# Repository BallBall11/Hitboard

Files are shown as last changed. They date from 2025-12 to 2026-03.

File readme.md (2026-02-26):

### HITBOARD 开源项目

Hitboard 是一个开源 Hitbox 项目，包含 Zero、Air 等不用型号以适应不同用户、不同场景的需求。它诞生于一个简单的需求：为何不能有一台既拥有键盘的紧凑布局，又具备 Hitbox 专业输入体验的设备？

本项目不仅提供可生产的文件，更完整记录了从 设计思路、CAD布局、PCB工业化 到 固件配置 的全流程。你可以直接使用，也可以将其作为起点，打造属于你自己的终极武器。

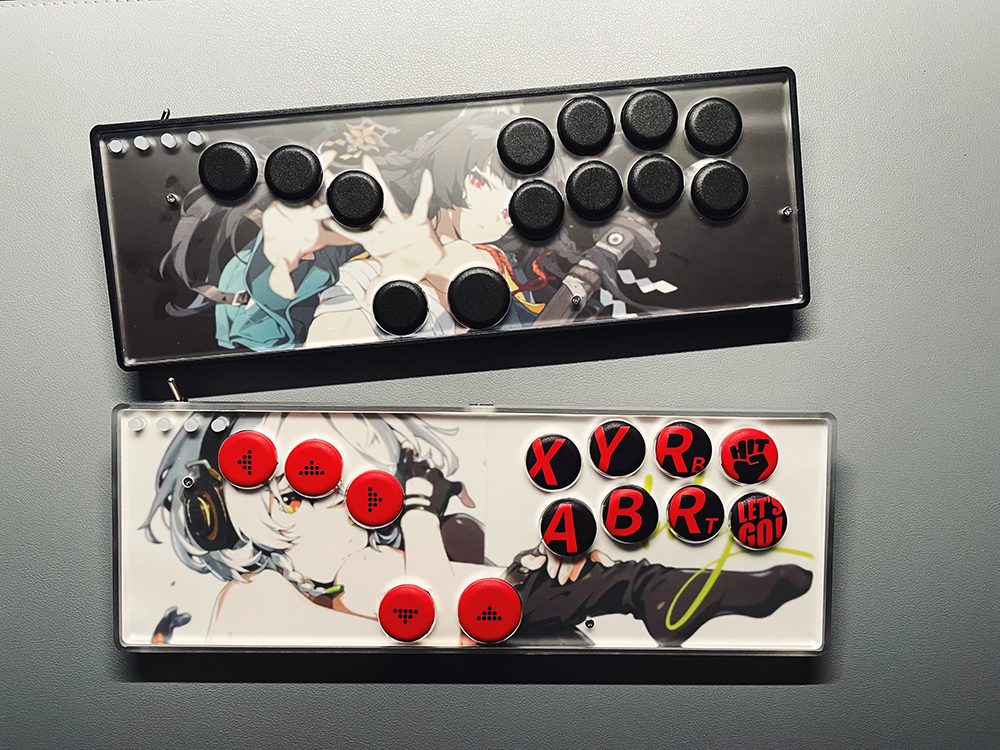
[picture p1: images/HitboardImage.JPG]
Hitboard成品图


#### 🎬 项目视频实录

本项目的完整诞生过程，已通过系列视频详细记录。如果你对背后的思考、踩坑的经历和具体的制作步骤感兴趣，强烈建议观看：

【【街霸6】180元手搓 Hitbox | 附材料清单设计源文件】 https://www.bilibili.com/video/BV1n8UQBeEs3/?share_source=copy_web&vd_source=521fa607e5f082de7ab25fcafb9cb9a2

【手搓Hitbox 第二弹：全程组装实录】 https://www.bilibili.com/video/BV15iUfBCE8V/?share_source=copy_web&vd_source=521fa607e5f082de7ab25fcafb9cb9a2

【手搓Hitbox 第三弹：生成CAD文件】 https://www.bilibili.com/video/BV1XumPBUEJE/?share_source=copy_web&vd_source=521fa607e5f082de7ab25fcafb9cb9a2

#### ✨ 型号说明
Hitboard Zero

从零开始的起点，为渴望亲手定义操控的创造者而生。纯亚克力多层结构，只需简单修改CAD文件即可调整布局，一切由你决定。这里仅提一套参考布局、PCB 源文件作为灵感，而非定死的答案。288×96mm键盘尺寸无缝融入桌面，双面壁纸让美学随你变换。它是你打造专属控制器的空白画布，也是通往深度定制的第一级台阶。

Hitboard Zero

Hitboard Air

像拼四驱车一样拼 Hitbox。基于3D打印技术实现，256mm宽度适配家用打印机。保留Zero的全尺寸按键布局，并提供更灵动的“拨片”加键。所有电路部分均为卡扣结构，可以方便的拆卸转移。

//由于卡扣结构的设计极其复杂，牵一发动全身。此型号提供全套 3D 打印文件作为标准答案。

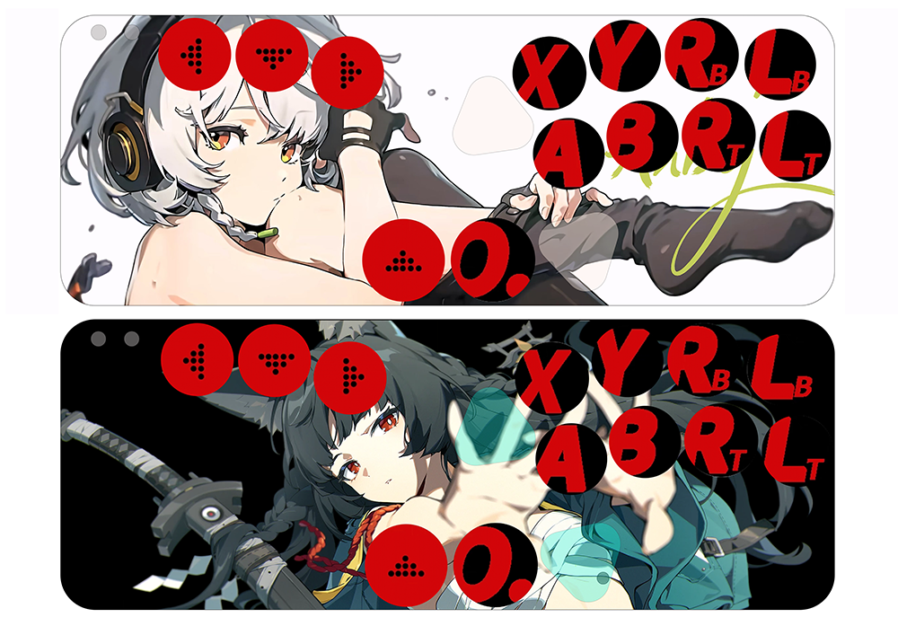
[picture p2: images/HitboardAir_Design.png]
Hitboard Air


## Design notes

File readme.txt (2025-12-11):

HITBOARD 开源项目

Hitboard 是一个专为键盘玩家设计的、高度紧凑、可完全自造的街机控制器（Hitbox）开源项目。它诞生于一个简单的需求：为何不能有一台既拥有键盘的紧凑布局，又具备 Hitbox 专业输入体验的设备？

本项目不仅提供可生产的文件，更完整记录了从 设计思路、CAD布局、PCB工业化 到 固件配置 的全流程。你可以直接使用，也可以将其作为起点，打造属于你自己的终极武器。

Hitboard成品图

🎬 项目视频实录
本项目的完整诞生过程，已通过系列视频详细记录。如果你对背后的思考、踩坑的经历和具体的制作步骤感兴趣，强烈建议观看：

【【街霸6】180元手搓 Hitbox | 附材料清单设计源文件】 https://www.bilibili.com/video/BV1n8UQBeEs3/?share_source=copy_web&vd_source=521fa607e5f082de7ab25fcafb9cb9a2

【手搓Hitbox 第二弹：全程组装实录】 https://www.bilibili.com/video/BV15iUfBCE8V/?share_source=copy_web&vd_source=521fa607e5f082de7ab25fcafb9cb9a2

【手搓Hitbox 第三弹：生成CAD文件】 https://www.bilibili.com/video/BV1XumPBUEJE/?share_source=copy_web&vd_source=521fa607e5f082de7ab25fcafb9cb9a2

✨ 项目特点
键盘布局，零学习成本：基于 GH60 键盘壳尺寸，沿用最熟悉的打字手位，上手即用。
全开源可定制：提供所有原始设计文件（CAD/PCB），你可以自由调整每一个按键的位置。
工业化 PCB 设计：采用专业 PCB 替代飞线，集成 WS2812B LED 灯带支持，稳定且易于焊接。
GP2040-CE 原生支持：完美兼容开源固件 GP2040-CE，享受持续的功能更新与强大的社区支持。
模块化设计：预留背光、热插拔摇杆模块接口，功能可自由增减。

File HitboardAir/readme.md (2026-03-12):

### Hitboard Air - 组装指南

### 准备工作：采购元器件

1. 下载网页工具：00_设计你的 Hitboard Air.html

2. 用浏览器打开该网页，设计你的 Hitboard。设计完成后，点击页面中的「导出产品配置」按钮，导出你的配置图片。

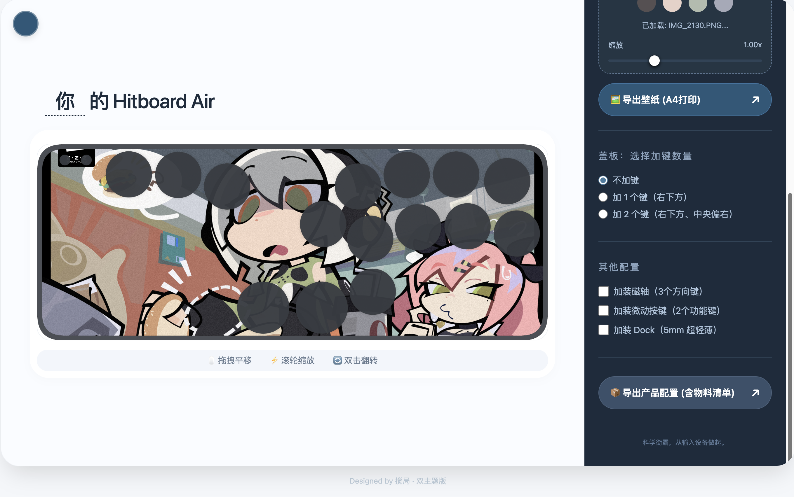
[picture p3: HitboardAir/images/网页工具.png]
HitboardAir 全部打印件


3. 根据配置图片中的物料清单，采购元器件、3D 打印套件。

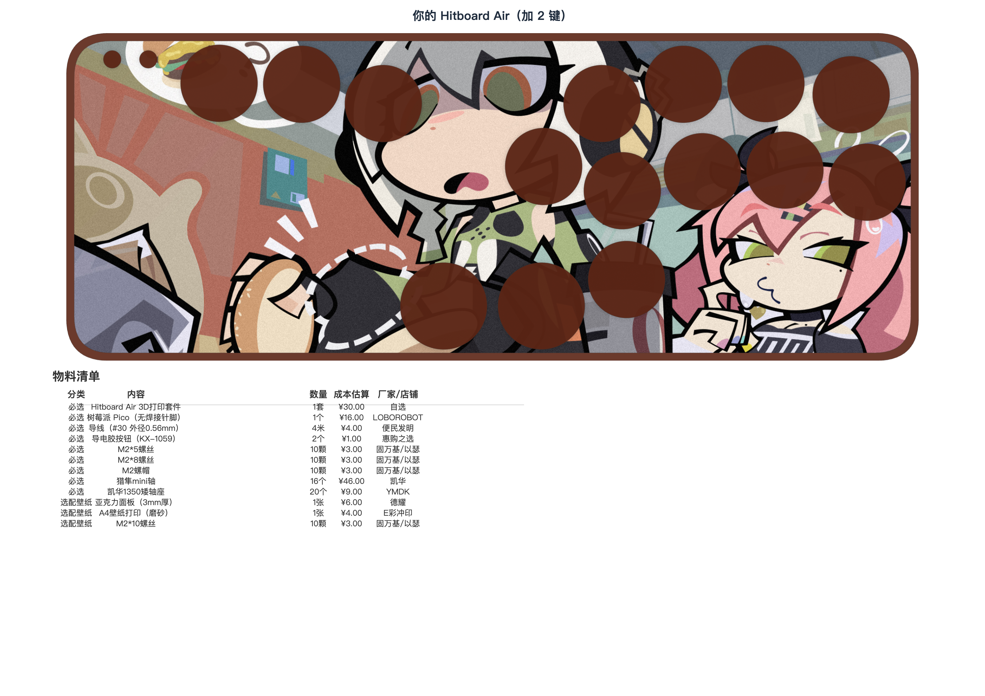
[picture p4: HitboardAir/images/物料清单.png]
HitboardAir 全部打印件


**3D 打印文件怎么选**

02_3D_Files 目录，包含两套 3D 打印文件，分别是：

「Hitboard Air - 圆润版」

「Hitboard Air - 硬朗版」

//两个版本只有外壳、按键的弧度有区别，内部零件通用。根据你喜欢的风格二选一，或全都选，即可。

HitboardAir 全部打印件

### 组装过程

### 第一步：给 Pico 刷入 GP2040 固件

1. 按住 Pico 复位按钮的同时，通过 typec 数据线连接 Pico 到电脑。此时 Pico 将会以 U 盘的形式出现。
    
2. 将固件「GP2040-CE_0.7.12_Pico.uf2」文件，拖拽到 Pico U 盘。
    
3. 等待几秒钟，Pico 会被重新识别为手柄。可以在手柄测试网页 https://hardwaretester.com/gamepad 查看手柄状态，用导线短接 GND 和任意信号引脚查看是否工作。

### 第二步：飞线连接元器件

打开「Pico背面图片」，观察的引脚示意图，了解引脚的基本情况。

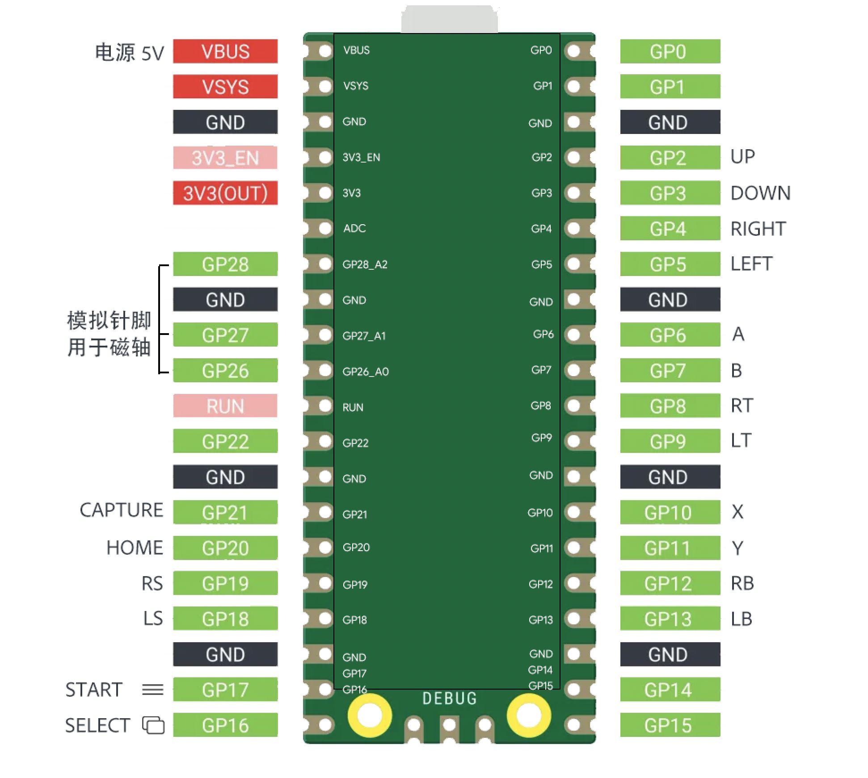
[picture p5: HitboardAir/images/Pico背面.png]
HitboardAir 全部打印件


1. 拿出「Hitboard Air 03 线路板」，板子上布满卡扣，依次将 Pico、轴座卡在对应的位置。

**注意！一定要是正面（有 USB 凸起）朝里，背面（绿色纯平面）朝向自己卡进去。**

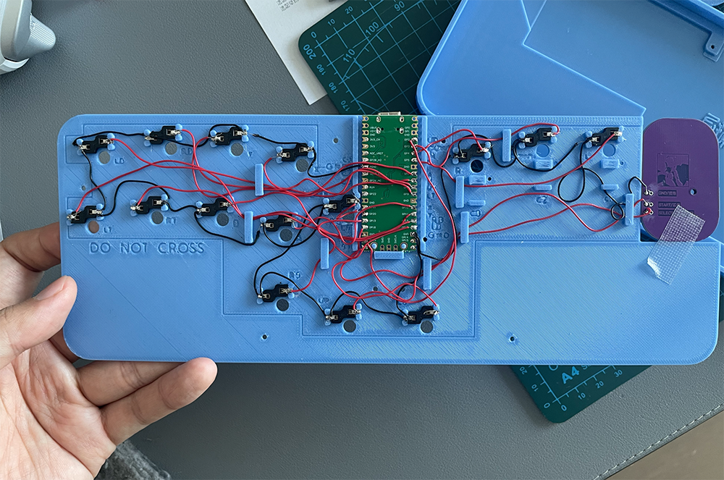
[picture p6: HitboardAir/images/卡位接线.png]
HitboardAir 全部打印件

    
2. 连接
    
    首先，留意线路板上的“警戒线”标注，警戒线内对应底壳空腔，表示线路可以被容纳。如果超出警戒线，则线路无法被容纳，组装时，无法放平整。

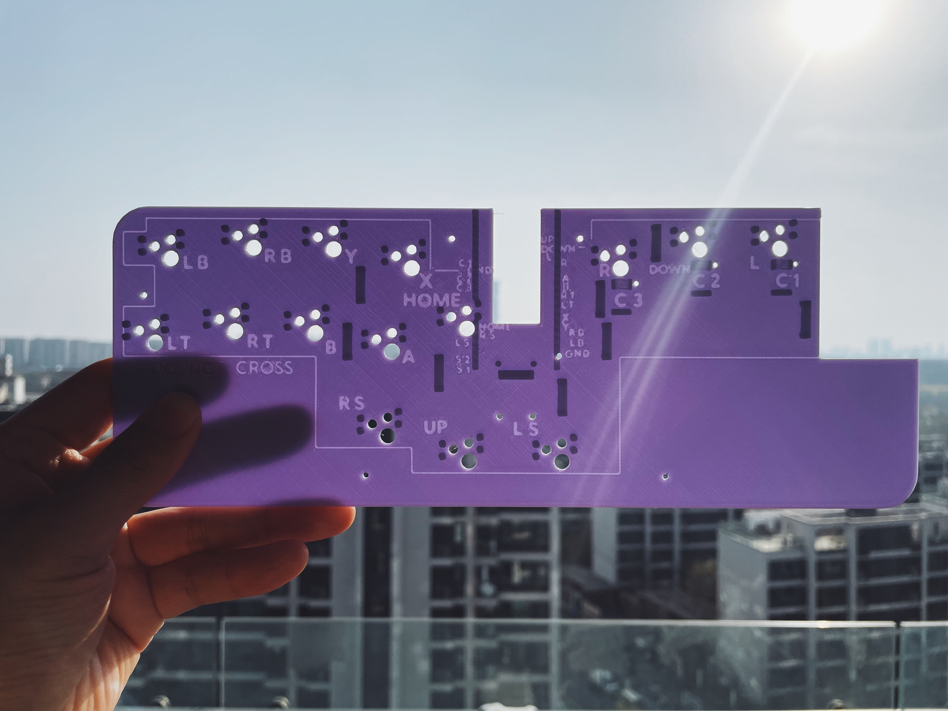
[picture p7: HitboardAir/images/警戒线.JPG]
HitboardAir 全部打印件


先来给每个按键接 GND。
    
    从 Pico 的任意 GND 方形焊盘，引出导线，将导线依次通过每一个轴座的任一引脚，焊接确保联通（或者缠绕连接）。这样就完成了按键的接地。
        
    将按键轴座另外一个引脚，接到对应的功能。比如方向键「Up」连接到 GP2 Up。
        
    把 4 个方向键、8 个功能键的轴座触点，通过导线，连到 Pico 对应的引脚。
        
    三个加键的轴座触点，连到 Pico 的 LS、RS、Home 引脚，后续需要在设置中，改为你需要的其他按键。

    Select、Start，默认使用导电胶+小电路板实现。把电路板上对应名字的焊盘，与 Pico 引脚相连即可。记得给小电路板连 GND。
        
    // 连接完成后，务必把 Pico 连接到电脑，用导线短接每个轴座的两个引脚。在手柄测试网页查看是否都能生效。
        
    // 如果不生效，检查是否虚焊，直到所有按键电路都正常工作。

### 第三步：组装所有板子

    将 03线路板、02定位板，依次放入04外壳。
    
    将轴体压入 02 定位板。//可以用手指挤压轴体左侧的外壳，让轴体不损耗卡扣
    
    放置导电胶按钮。
    
    准备盖板。通过 04 外壳的卡扣卡好即可。
    
    // 如果想要更牢固的固定盖板：
    
        先将 M2 螺丝帽，放入盖板背面的隐藏式螺帽仓。
    
        盖好盖板到外壳。
    
        从外壳背面，拧 6 颗 8mm M2 螺丝。
    
    从00按键中，取下按键，对应按键位置，一一装入。

### 软件设置

#### 按键配置

1. 按住 Start 按键的同时，通过 typec 连接电脑。
    
2. 访问 GP2040 Web 配置界面（通过 USB 连接后访问 192.168.7.1）
    
3. 点击「功能配置-GPIO 引脚配置」，将 LS、RS、Home 等按键，改为需要的按键。
    
    如果忘了哪个按键对应哪个。点击网页中的「引脚查看器」按钮，在 Hitboard 上按下需要配置的按键，网页会显示引脚编号（如果第一次检测无效就关闭弹窗再次点击）。
        
    在按键列表中找到对应的引脚，编辑按键即可。
        
#### 手柄性能设置：//必做

1. 点击「设置-游戏手柄设置」。
    
2. 将 SOCD 清理模式，改为「后输入优先」。
    
3. 将去抖延迟，改为 0 毫秒。

### 选配组件

#### Dock

先把本体滑入Dock上半。（滑入前，将 2 颗 M2 螺帽装入上半螺帽仓）

再把Dock下半卡入本体。

将 5mm M2 螺丝，分别从 Dock 左右两侧的螺丝孔拧入，即可完成固定。

锁线器：
    
    将 12 颗小磁铁，6 颗一组，压入锁线器的磁铁仓。
    
    将 6 颗小磁铁，3 颗一组，压入 Dock 的磁铁仓。
    
    将锁线器快装到 typec 数据线，即可使用磁吸锁线功能。

#### 盖板和壁纸

通过网页工具，制作下载壁纸图片。以 A4 尺寸打印，获得纸质壁纸。

对壁纸裁剪、打孔，取下 3D 打印盖板，替换为壁纸、亚克力盖板即可。

// 亚克力生产的 CAD 文件：其他/CAD 文件/Hitboard Air 亚克力.dwg

#### 磁轴

星磁mini轴的弹簧比较硬，我们先对弹簧手感进行调优。

剥开轴体，取下弹簧。将弹簧剪掉1/3。剪下的弹簧不要丢掉，以后可以用在功能键上。磁轴结构非常简洁，圆形磁铁对准圆形磁铁孔，装回即可。

这样轴体的手感就非常丝滑软弹了。如果想要磁轴、机械轴共存，剪掉磁轴右上方的塑料卡针即可。

搞定机械部分之后，我们开始处理电路。拿出选配零件中的霍尔传感器。窄面朝上，卡入线路板专用位置。传感器从右边起，分别是信号引脚、GND、3V3电压输入。每个传感器一一对应连接。

然后进入最后的软件校准环节。进入网页配置界面，
先进入LED配置，把默认占用的28引脚修改为其他引脚，释放这个模拟引脚。

然后进入插件设置，确保其他设置没占用模拟引脚的情况下，进入霍尔设置。

设置直连，26、27、28。然后对每个引脚绑定手柄键值，然后校准。

这里可以设置一个比较短的触发行程，让方向键快于拳脚键。对搓招儿的时间窗口比较有利。

最后保存触发值，重启设备。你的 Hitboard 就拥有了最顶级的性能。

### 关于手工缠线（免电烙铁）

手工缠线比电烙铁还要简单。要点是小孔缠线的技巧。
掐掉导线20cm左右的绝缘皮，对折导线头。

穿入对应的引脚焊盘孔，旋转Pico或导线，你就获得了由四股导线固定的引脚线
比单根导线有更大的强度和更大的接触面积。

绑定所有导线后，像装机走线那样集中安排走线就行了。

轴座端，缠两圈线，压扁轴座铁皮，一路引脚就固定好了。

轴座新增2个小过孔，方便GND裸导线从背面走线。

之后就是重复操作，不再赘述。

### 总结

我们从一堆散件开始，亲手完成了固件烧录、线路连接、整机组装和软件配置。最终得到的，不只是一台Hitboard——更是从零到一，把想法变成实物的能力。

科学街霸，从输入设备做起。Hitboard，让创造回归简单。

**【完】**

项目贡献者名单：@搅局无敌 @JennyPeng @匈牙利山猫 @Rev01ution

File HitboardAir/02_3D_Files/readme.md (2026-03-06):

### Hitboard Air - 3D打印设置

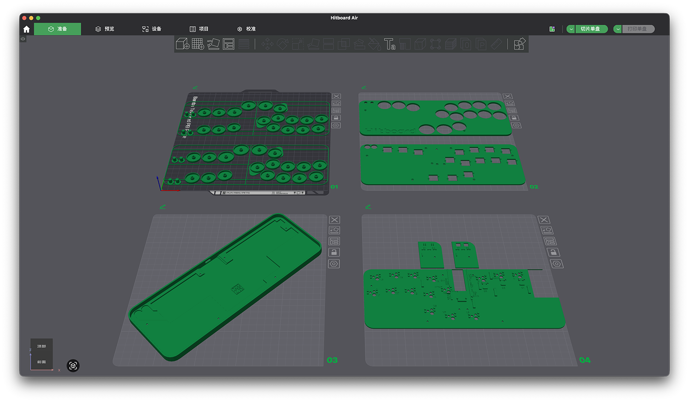
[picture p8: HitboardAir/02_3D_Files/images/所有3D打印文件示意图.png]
HitboardAir 全部打印件


#### 1. 文件说明

#### Hitboard Air 双版本 · 刚柔并济

**文件说明**

Hitboard Air 提供两种性格的版本——刚版与柔版。外壳、按键、Dock 三处的倒角设计，决定了设备整体的气质与手感。你可以根据自己的偏好，选择与你契合的那一款。

**刚 · 方正利落**
    
平整的极客体验。

    边缘干脆，线条直接。2.4mm 倒角仅做必要圆滑，保留直角带来的精准感。适合追求硬朗风格、喜欢清晰反馈的你。放在桌上，它是一块冷峻的金属感面板；握在手里，每一个棱角都在提醒你：这是一件趁手的工具。

**关键词：** 利落、精准、克制

**柔 · 圆润亲和**

温润的舒适体验。

    圆角过渡自然，握持更贴合手掌。每一个边缘都经过细致打磨，触感如鹅卵石般温润。适合长时间使用、偏爱柔和手感的你。它不会喧宾夺主，只是安静地承托你的每一次操作。

**关键词：** 圆润、舒适、包容

选择你的版本

刚与柔，没有好坏，只有不同。你的设备，该有你的性格。

##### 00_按键

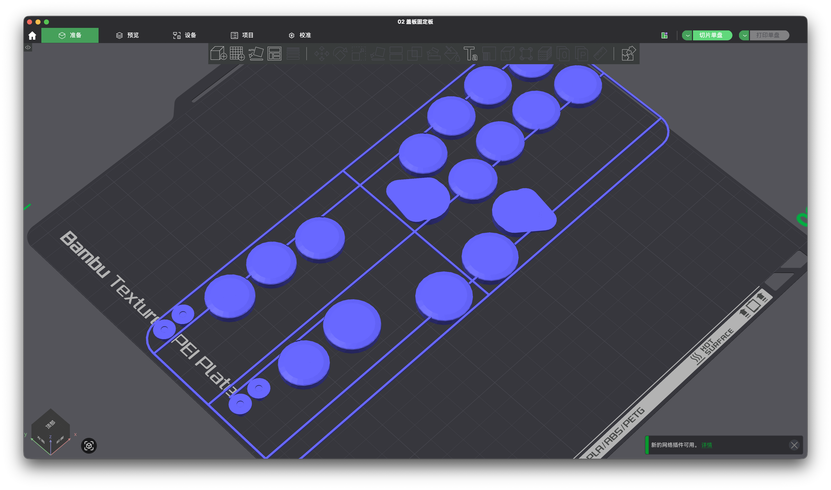
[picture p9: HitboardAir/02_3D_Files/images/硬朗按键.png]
HitboardAir 有刻键帽


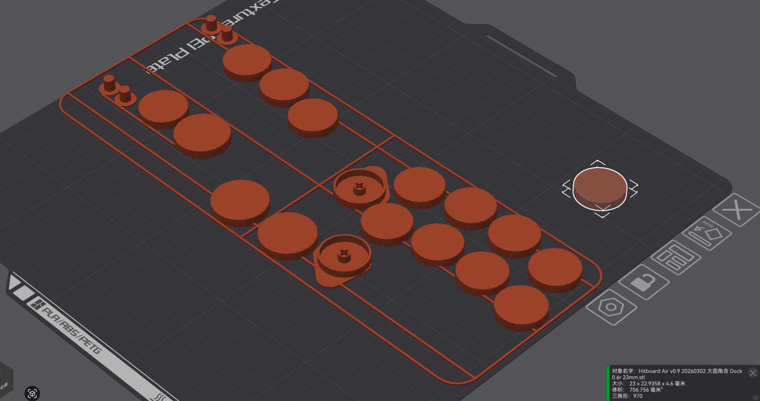
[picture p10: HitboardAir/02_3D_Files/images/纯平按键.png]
HitboardAir 有刻键帽


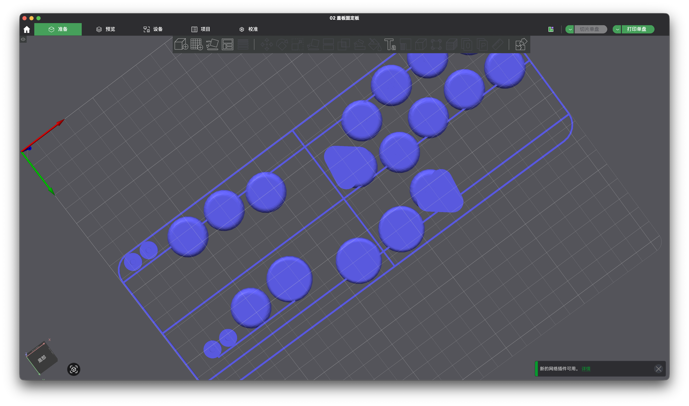
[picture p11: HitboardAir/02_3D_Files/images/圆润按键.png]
HitboardAir 有刻键帽


**键帽类型**

按键类型    命名    英文名    说明
2.5mm斜切    硬朗按键    Edge Key    线条硬朗，反馈清晰
0.6mm圆角    纯平按键    Flat Key    视觉纯平，手感顺滑不割手
3mm圆角    圆润按键    Round Key    明显圆角，手感柔和

**键帽触感**

按键根据键帽的朝向，有键帽朝上（正打）、键帽朝下（反打）两种方式。

正打能提供比较好的表面平整度，缺点是按键的确认感会不清晰。

反打按键的特点是，利用热床的颗粒，反打获得的表面随机颗粒效果，可以欺骗触觉（类似相机上的颗粒喷涂）。

// 注意：反打按键，需要在软件里把文件翻个朝向（也可以点击软件的「自动朝向」）。

**键帽刻字**

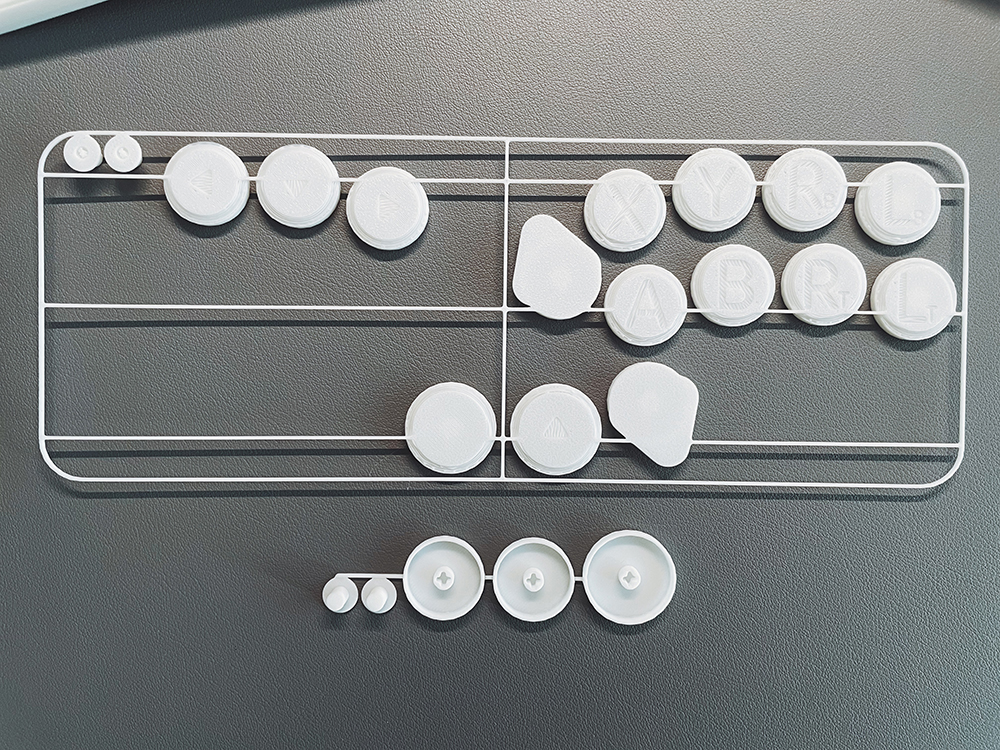
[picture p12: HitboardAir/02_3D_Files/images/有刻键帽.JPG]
HitboardAir 有刻键帽


有刻按键整体视觉上会好看一些，但会牺牲手感。推荐无刻。 （有刻在 More 文件夹中，有需要的自取）

##### ButtonsSystem

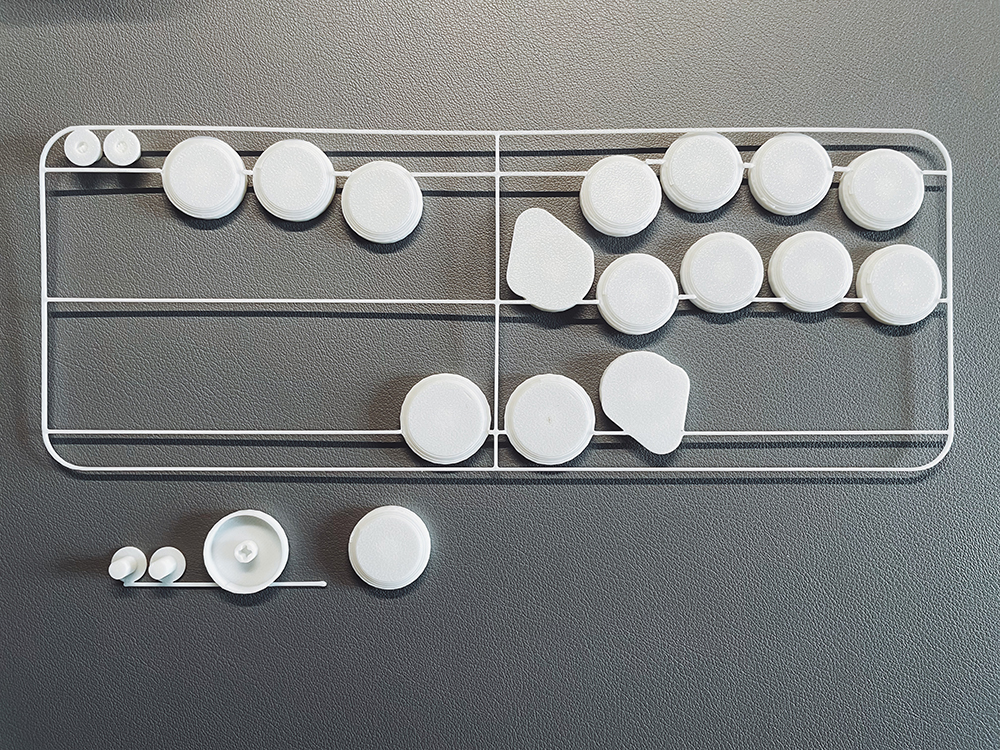
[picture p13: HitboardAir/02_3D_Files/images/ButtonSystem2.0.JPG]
HitboardAir 有刻键帽


按键通过中框串联，不会掉的到处都是。能一定程度防止运输过程丢按键。每套按键都提供了一组独立的备用按键，包含 2 个功能键、1 个 23mm 按键，1 个 26mm 按键。
        
中框已升级为 ButtonsSystem2.0，可以轻松的从框体取下键帽。喜欢拼高达，喜欢口水钳剪零件的同学可以打印这两套按键。

ButtonsSystem 已适配的按键组：
    
    00_Hitboard_Air_硬朗按键_全按键_无刻_带框_反打

    00_Hitboard_Air_圆润按键_全按键_无刻_带框_反打

##### More 文件夹

提供了更多的按键选项，进阶 3D 打印玩家可以多尝试不同的组合。

// 后续会持续研究 3D 打印按键，欢迎大家反馈这方面的需求。

#### For A1mini 180x180 文件夹

** 之后会适配 Amini 打印机的 180x180 尺寸，让每一个人都能享受到科技乐趣。 

** 01_盖板

用作产品上盖。
// 如果有自定义壁纸的需要。可以拿 CAD 文件，去花几块钱买一个 3mm 磨砂亚克力盖板。

盖板新增了 Logo
    
        “跟人约战街霸，对方没听过 Hitboard。你掏出设备，一个没有 Logo 的 3D 打印件——对方看了一眼，没说话。”

        “你知道他在想什么：山寨货。”

        “尴尬。”

        “Logo 不一定为了让别人认出来。有时候，是为了不让别人认错。”

** 02_定位板

// 定位板、轴座板，支持凯华矮轴：猎隼 mini、紫鸳、孤岛粉 mini、星磁 mini 等

用于支撑、固定机械轴。
    
安装轴体时，可以用手指按紧机械轴左侧的塑料臂，然后再往里按。这样能有效提升卡位结构的寿命。

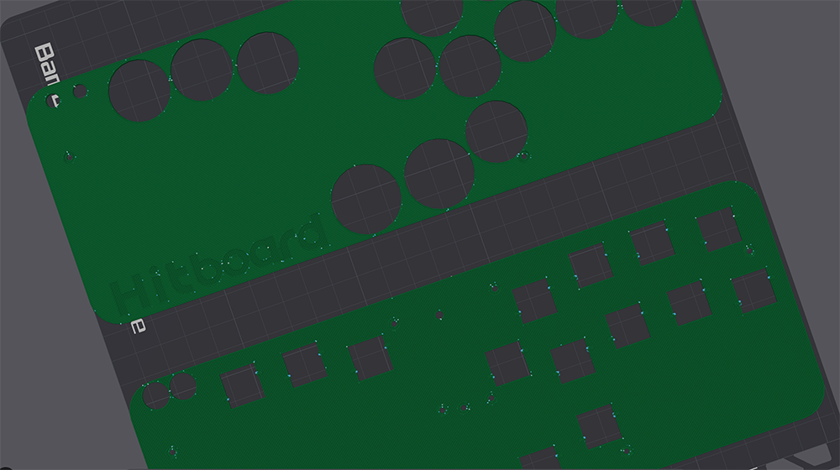
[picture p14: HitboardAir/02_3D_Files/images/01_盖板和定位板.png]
HitboardAir 按键


** 03_线路板
    
用于安装轴座、Pico 主板、飞线、功能键微动按钮。
    
线路板有凹印文字，标记了引脚。飞线时可参考标记接线。
    
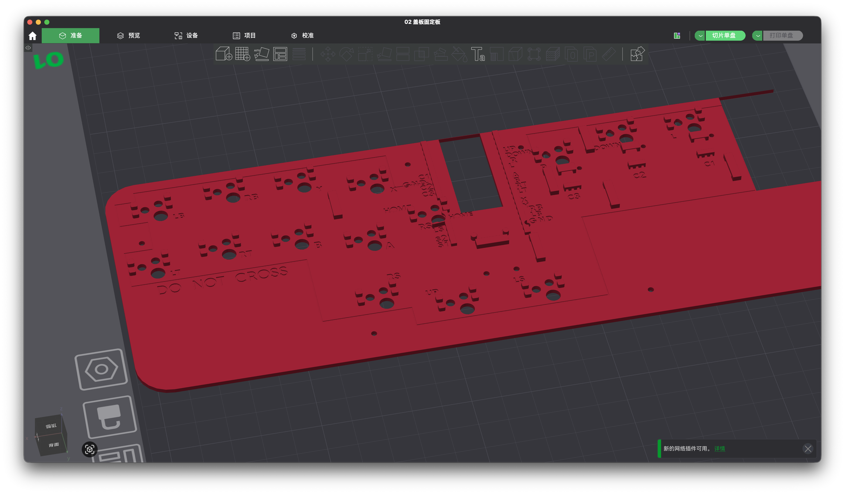
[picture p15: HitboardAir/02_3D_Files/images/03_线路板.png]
HitboardAir 线路板

    
「more」目录，提供了单独的「功能键小板」文件。方便单独补零件。

** 04_底壳
    
底壳提供 9.3mm（超薄）、9.7mm（中薄）两个文件。
    
这里优先推荐 9.3mm 外壳，因为 9mm 左右恰好能让键盘的厚度没有存在感，不硌手。9.7mm 的厚度，键盘底部边缘会有存在感，请知。

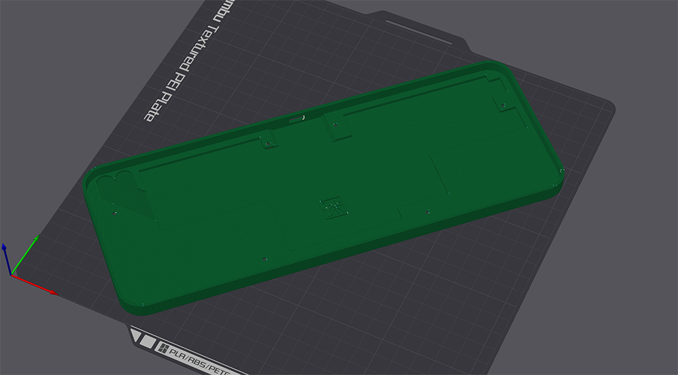
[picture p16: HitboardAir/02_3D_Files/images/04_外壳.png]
HitboardAir 按键


关于边框：默认提供 2.4mm 的边框，能让彩色外壳线条更美观。//more 文件夹有原 2mm 边框，有需的自取。两种边框外圈都是一样大（260x100）

#### 2. 打印设置

** 支撑设置

01、02、04 板子，按默认面打印。00按键、03板子，需要在打印软件里翻个面。// 点击拓竹的自动翻面就可以

用不用支撑差别不大，可以开启树状支撑保险一点。

// 经常为了赶时间开狂暴模式打印，狂暴模式下出品质量也可以，因为基本都是垂直件没有悬浮。

** 朝向设置

04 外壳，倾斜 45 度打印，能让打印机的纹路横竖走，而不是 45度倾斜走。这样纹路会更方正、更有稳定感。。

00、01、02、03，用默认的朝向打印，45 度纹路，视觉上减少存在感。

#### 3. 打印材料

Hitboard Air 是基于 PETG 材料设计，有足够的强度和耐久度，计划长时间使用的话推荐使用 PETG 作为打印材料。

// 鉴于很多人的 3D 打印机只能打 PLA，对 PLA 也做了打印测试：精度、强度都还不错。长时间使用耐久度待观察。

// 注意！PLA 高温下容易形变，打印完成后，务必等板子冷却后，再取。否则可能会让板子弯曲。

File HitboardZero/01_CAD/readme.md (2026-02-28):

### Hitboard Zero CAD 使用说明

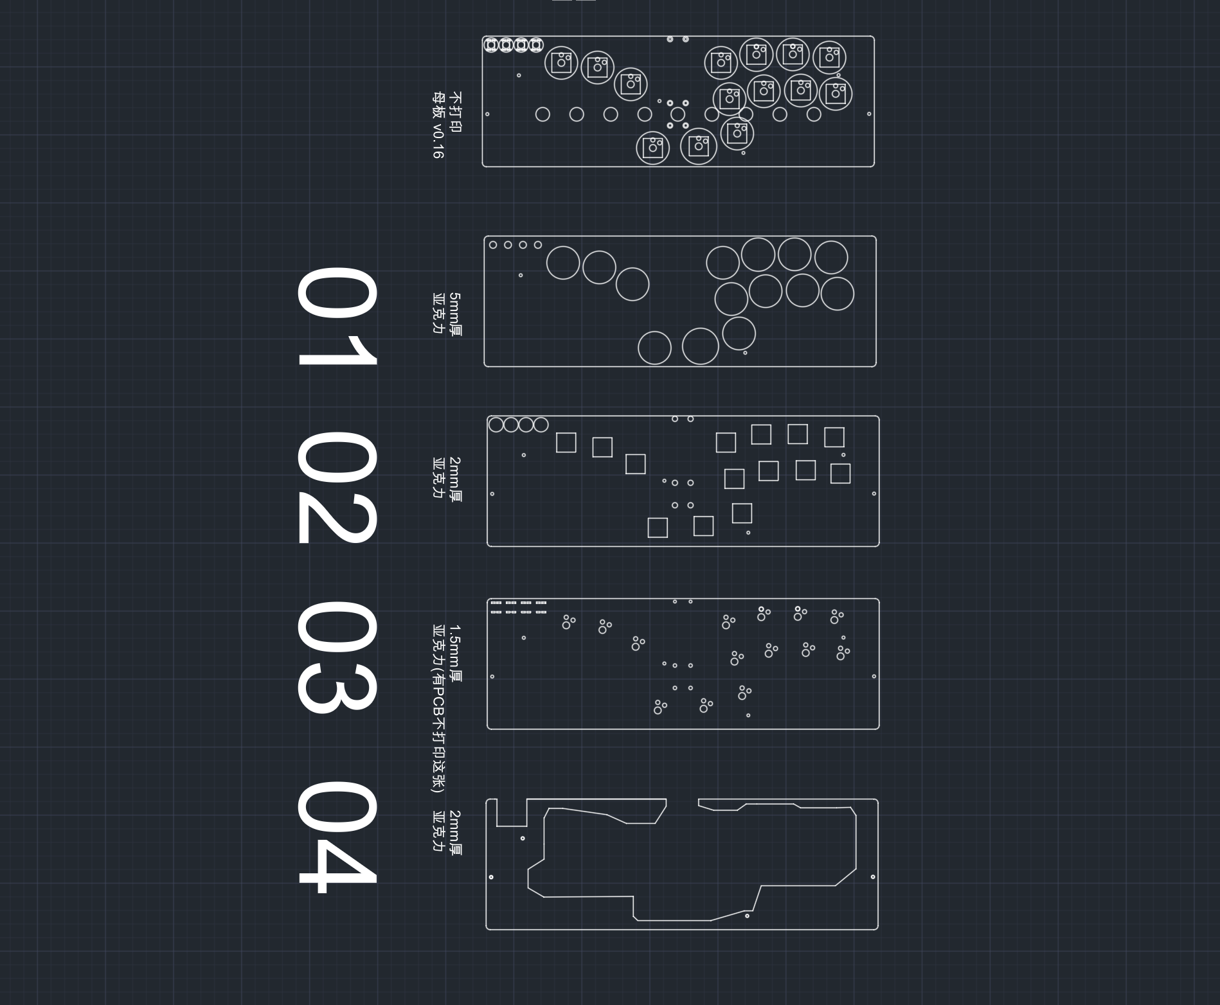
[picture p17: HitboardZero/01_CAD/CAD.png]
Hitboard成品图


#### 01 盖板

3-5mm 厚

放在顶层起到支撑手掌和展示壁纸的作用。一般采用透明亚克力或磨砂亚克力材质。

// 如果是亮色的壁纸，磨砂亚克力可以很好的柔光。如果是暗色的壁纸，透明亚克力可以让黑色更深沉。

#### 02 定位板

2mm 厚

14x14 的开孔，用于固定键盘轴体，并支撑敲击按键时的力。
// 中间有两组开孔，用户容纳螺丝的螺帽。

#### 03 轴座板

1.5mm 厚

用于支撑机械轴的轴座。将轴座插入每个按键的两小孔，并使用胶水固定。
// 中间两组螺丝孔，用于固定 pico。

#### 04 支撑板

2mm 厚

用于制造空腔，容纳轴座、pico、飞线。

// 顶部横梁默认是不断开的，提供更好的支撑性。如果是 typec 中央开孔，可以自行剪断。

#### 05 底部壁纸板

1mm 厚

用于支撑壁纸。//背面不放壁纸就不需要打印

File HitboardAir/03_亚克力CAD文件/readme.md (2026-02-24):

### Hitboard Air - CAD 说明
文件中为 Hitbox 的盖板。提供了 A、B、C 三个型号：

    A 带有两个加键（右手大拇指右侧、A 与 X 的左侧）

    B 只带一个加键（右手大拇指右侧）

    C 不带加键

// 下单无需 CAD 程序，根据型号列表报给商家就可以。

// 定位板是按照 2 个加键设计的卡位凸起，如果选择了 B、C 盖板，把定位板上的凸起剪掉就可以。

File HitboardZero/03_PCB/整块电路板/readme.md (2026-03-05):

### Hitboard Zero PCB（电路板） 说明 

鉴于市面上的 GH60 壳子五花八门，不规格。忙完这一阵子，会集中出一个高兼容性的 PCB。

敬请期待。

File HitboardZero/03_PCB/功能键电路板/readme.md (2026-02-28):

### Hitboard Zero PCB（电路板） 说明
使用亚克力和飞线作为电路

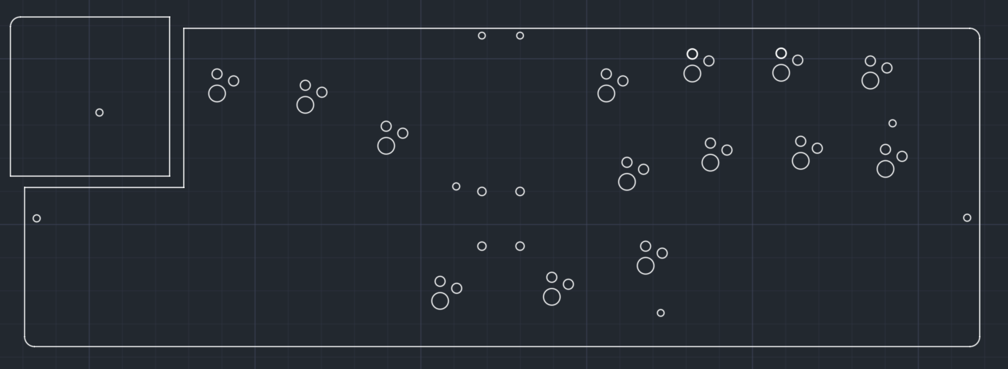
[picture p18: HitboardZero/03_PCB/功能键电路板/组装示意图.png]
Hitboard成品图


「03 轴座板」左上角设计了一个 48x48 的缺角。只需要使用嘉立创免费券，打印一个 48x48 的功能键电路板，就可以替代掉之前铜箔胶带贴电路的操作，更简单、更稳定。

// 推荐最开始使用飞线方案。因为把 Pico 焊接到 PCB 之后，几乎无法无伤拆解。等验证找到适合自己的布局之后，再考虑 PCB。

// PCB 相比飞线，所需要的焊点数量是一样的，并不会省时间。PCB 制造耗能、耗材料，不环保，不建议使用大块的 PCB。

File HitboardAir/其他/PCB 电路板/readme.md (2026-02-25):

### Hitboard Air - PCB（电路板） 说明
Hitboard Air 的设计初衷是模块化组装，飞线连接。不需要整块的电路板。

加入小电路板的目的是，让小朋友或者萌新能接触到最简单的PCB电路，对电子工程产生一些模糊的概念。

// 3D 打印文件，03 线路板中附带的「功能键零件」不论是手搓导电电路，还是使用微动按键，都能实现很好的功能键体验。

// 可以不使用此 PCB。

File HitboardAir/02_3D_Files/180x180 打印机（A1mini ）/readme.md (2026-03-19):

### Hitboard Air - For A1mini

20260319
-大幅增强了 A1mini 版本的结构强度。

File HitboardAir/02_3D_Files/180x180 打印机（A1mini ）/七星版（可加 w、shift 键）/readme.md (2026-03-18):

### Hitboard Air - For A1mini

00 按键、04 外壳，分为硬朗版和圆润版，根据自己的喜好二选一，或全都选。

01 盖板、02 定位板、03 线路板，是硬朗、圆润通用的，逐个打印。

// 盖板文件中，有全套封帽（包括摇杆封帽），根据自己需求自定义。
// 需要更多配件，去：HitboardAir/More - 更多配件/

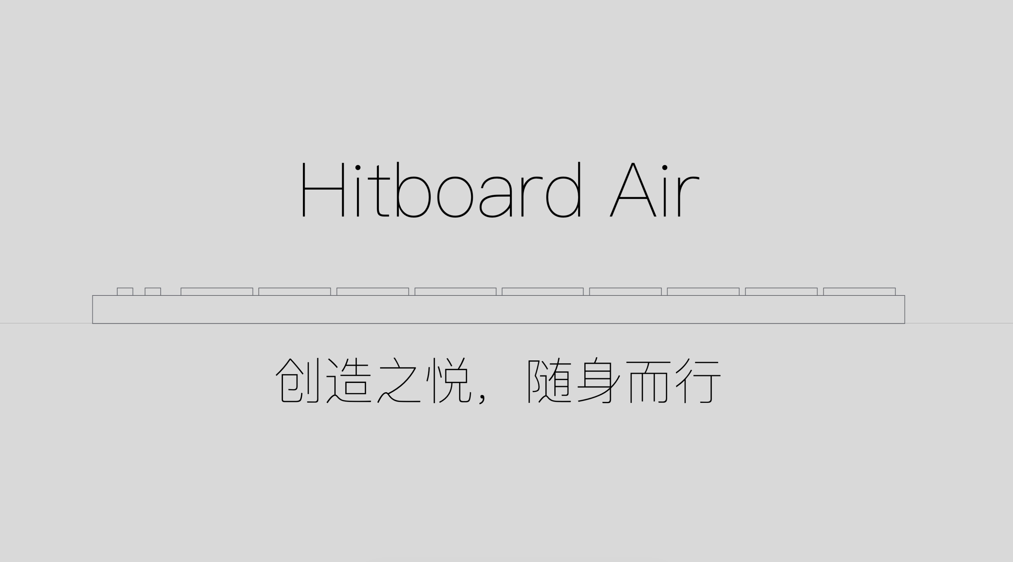
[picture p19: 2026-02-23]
HitboardAir/images/封面.png

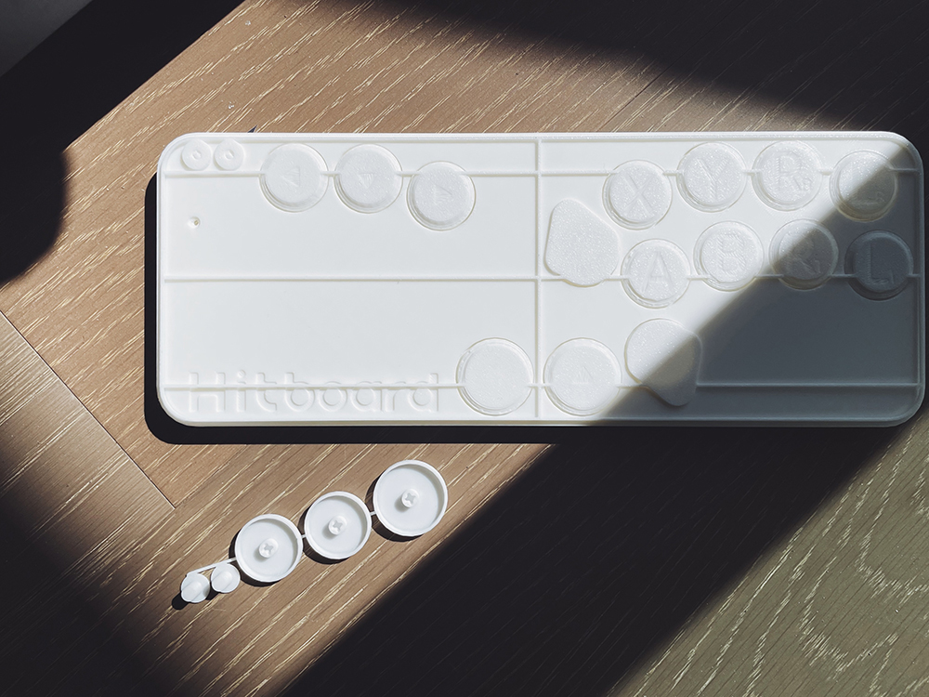
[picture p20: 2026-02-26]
HitboardAir/02_3D_Files/images/产品实拍_PLA.jpg

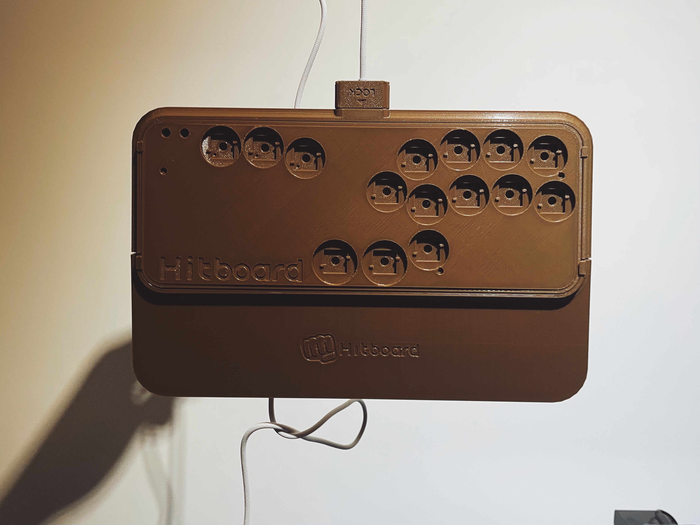
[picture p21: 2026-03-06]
HitboardAir/images/Dock.JPG

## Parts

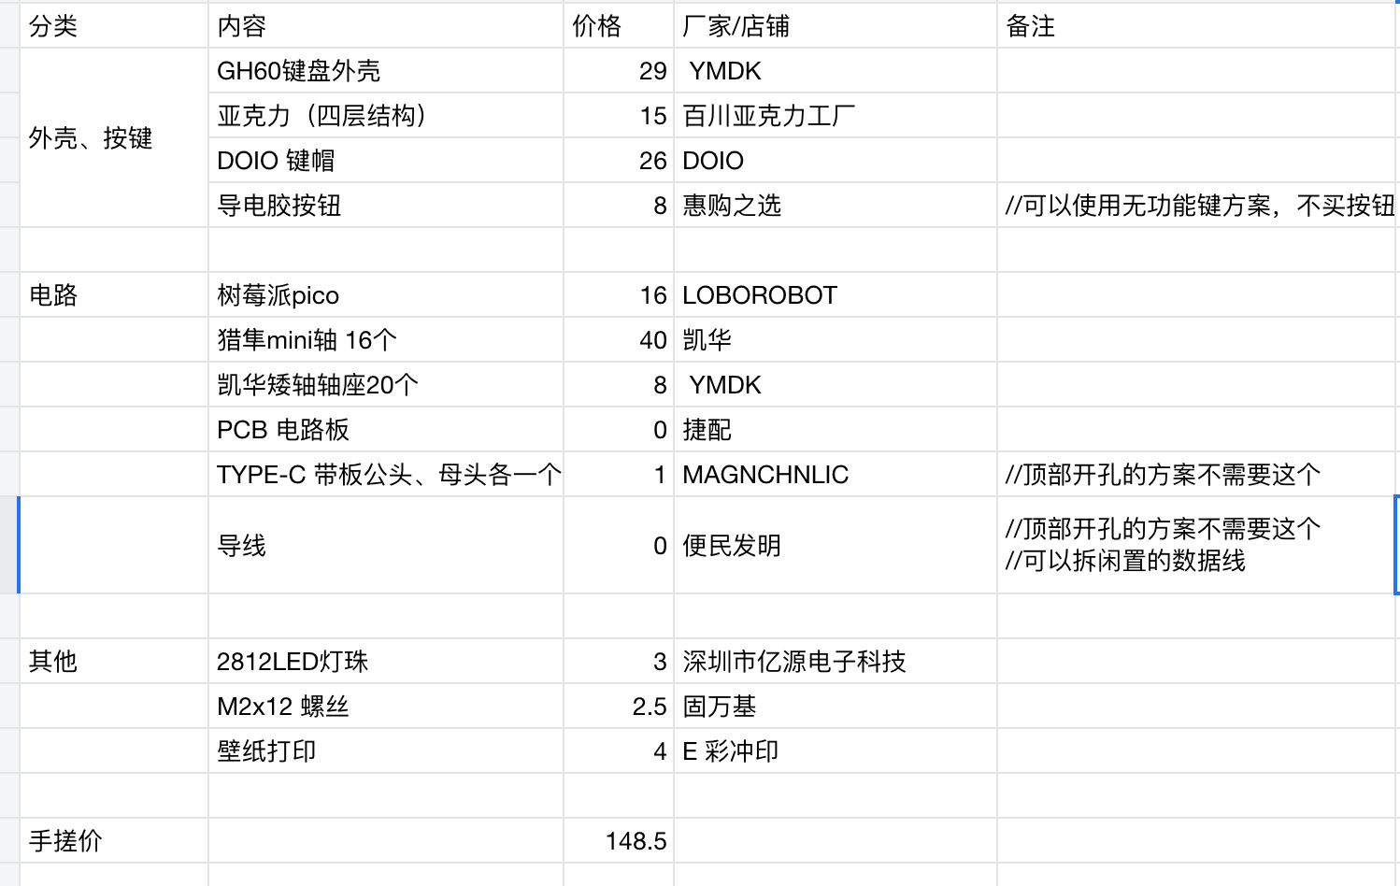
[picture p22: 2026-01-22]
HitboardZero/HitboardZero 物料清单.png

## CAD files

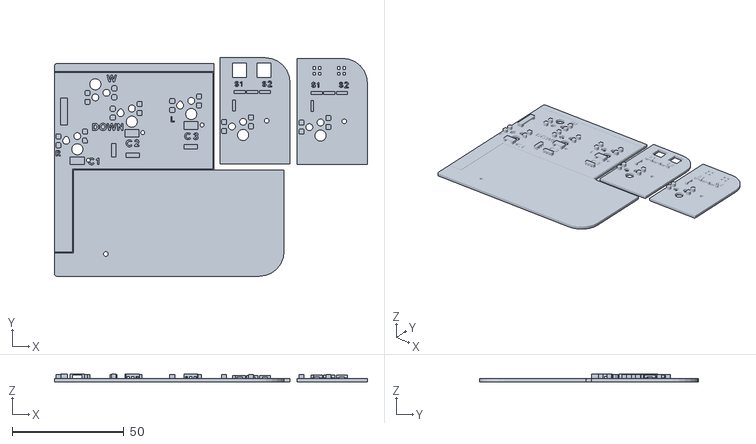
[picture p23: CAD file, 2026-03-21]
HitboardAir/02_3D_Files/180x180 打印机（A1mini ）/七星版（可加 w、shift 键）/圆润/03_线路板_左半.stl
140.1 x 97.8 x 3.50

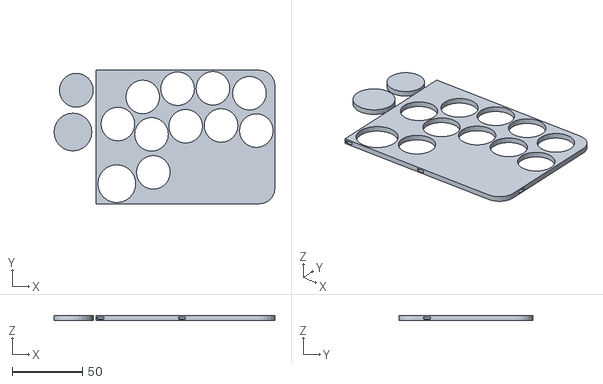
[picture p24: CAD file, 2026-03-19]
HitboardAir/02_3D_Files/180x180 打印机（A1mini ）/对称版/圆润/01_盖板_右半.stl
157.5 x 95.2 x 3.40

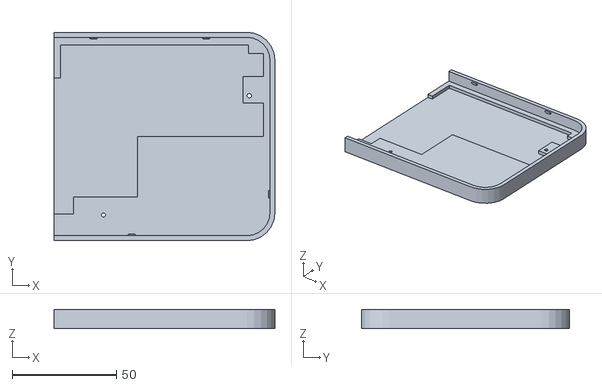
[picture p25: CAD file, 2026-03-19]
HitboardAir/02_3D_Files/180x180 打印机（A1mini ）/对称版/硬朗/04_外壳_硬朗_右半.stl
106.0 x 100.0 x 9.30

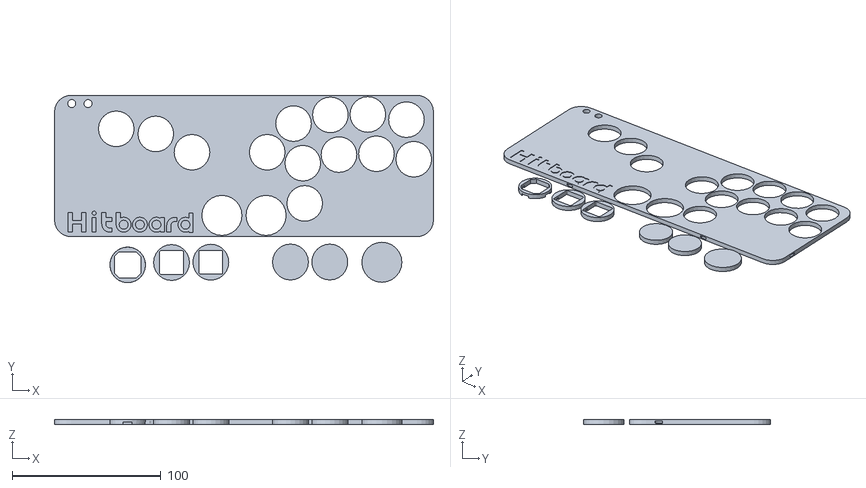
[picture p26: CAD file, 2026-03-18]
HitboardAir/02_3D_Files/Hitboard Air - 七星版（拳皇:绝区零:音游）/More/01 盖板 no w shift.stl
255.2 x 126.2 x 3.40

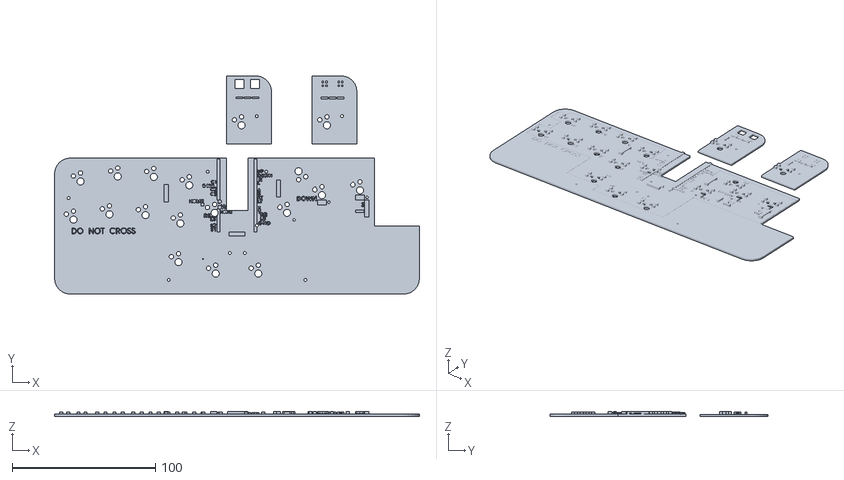
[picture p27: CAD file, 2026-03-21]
HitboardAir/02_3D_Files/Hitboard Air - 七星版（拳皇:绝区零:音游）/圆润线条/03 线路板.stl
255.2 x 152.6 x 3.50

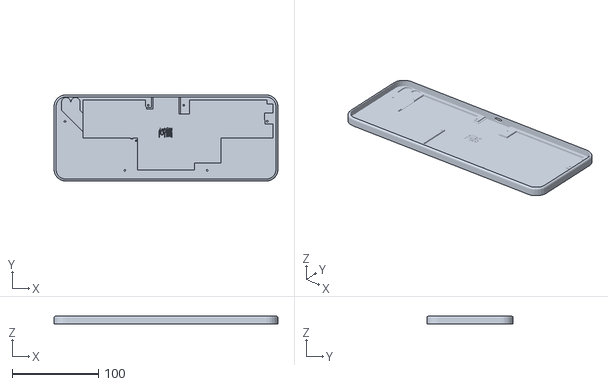
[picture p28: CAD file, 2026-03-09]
HitboardAir/02_3D_Files/Hitboard Air - 圆润版/ .stl
260.0 x 100.0 x 9.30

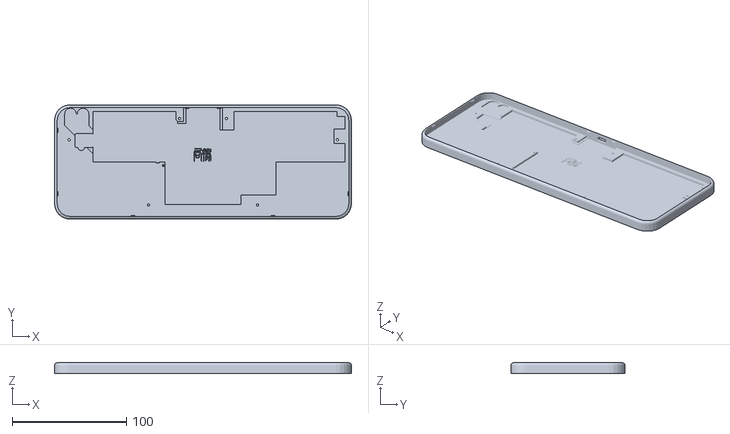
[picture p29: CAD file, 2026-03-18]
HitboardAir/02_3D_Files/Hitboard Air - 对称版（街霸特调）/圆润线条/04_外壳.stl
260.0 x 100.0 x 9.30

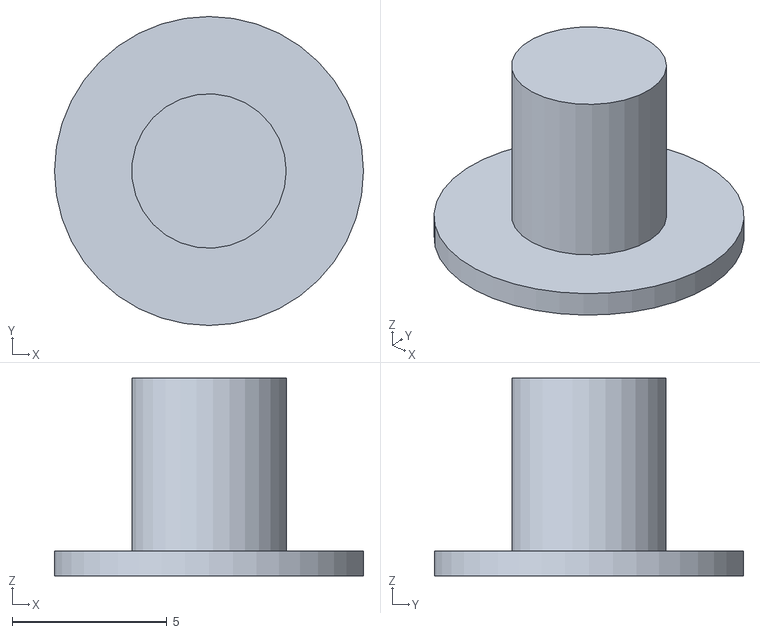
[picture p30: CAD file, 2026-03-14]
HitboardAir/02_3D_Files/More - 更多配件 /00_按键配件/配件_功能键/功能键单个.stl
10.00 x 10.0 x 6.40

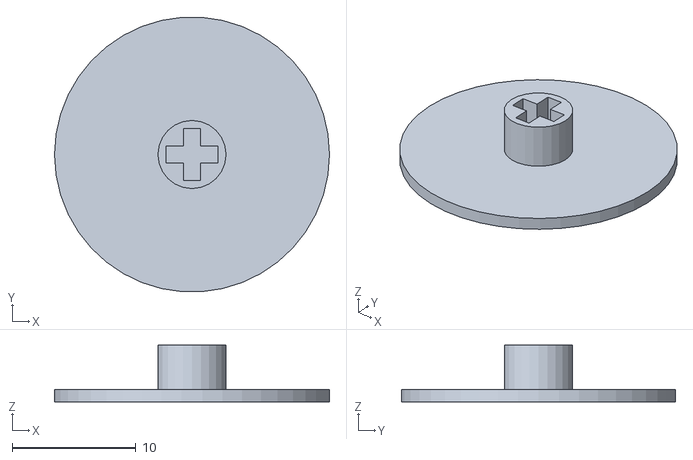
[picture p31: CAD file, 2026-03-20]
HitboardAir/02_3D_Files/More - 更多配件 /00_按键配件/配件_加键/圆形（22mm 直径）.stl
22.2 x 22.1 x 4.60

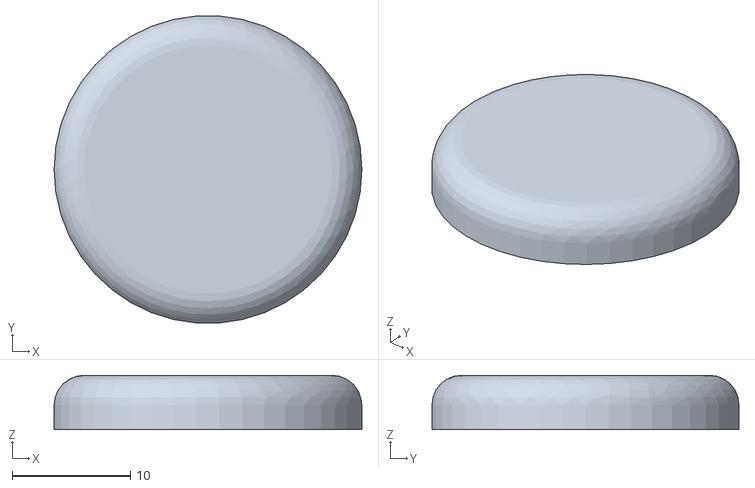
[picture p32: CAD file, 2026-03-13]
HitboardAir/02_3D_Files/More - 更多配件 /00_按键配件/配件_标准按键/00_圆润按键 （单个）/完美圆润 26mm.stl
26.0 x 26.0 x 4.60

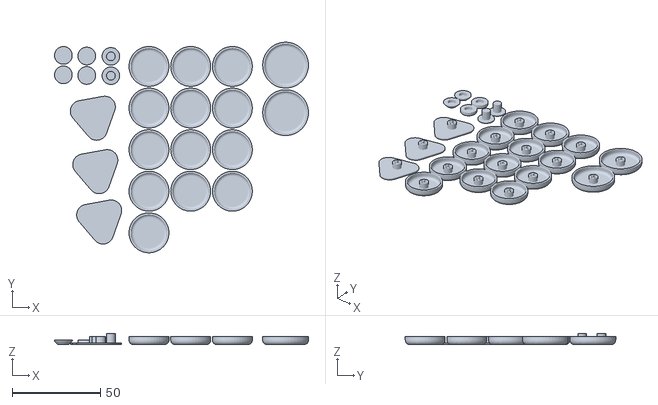
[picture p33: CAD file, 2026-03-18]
HitboardAir/02_3D_Files/More - 更多配件 /00_按键配件/配件_标准按键/00_按键_圆润整套反打.stl
144.2 x 119.5 x 6.40

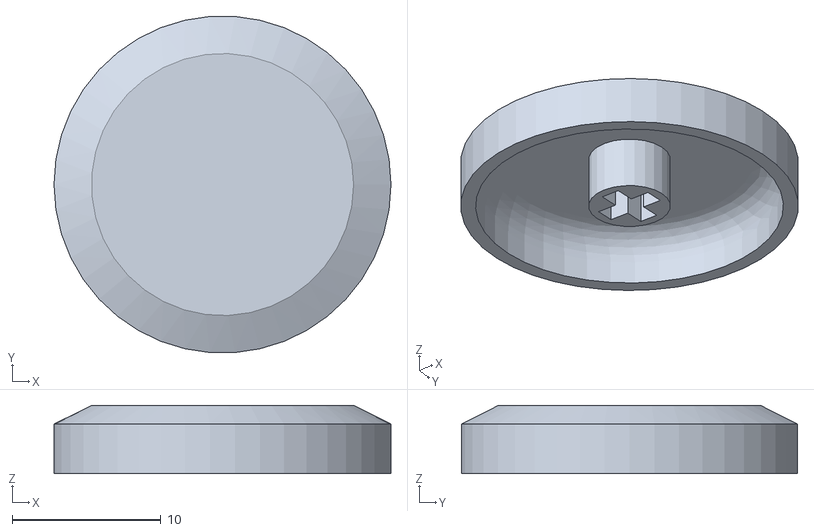
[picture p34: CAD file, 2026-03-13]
HitboardAir/02_3D_Files/More - 更多配件 /00_按键配件/配件_标准按键/00_硬朗按键（单个）/完美硬朗 23mm.stl
22.7 x 22.6 x 4.60

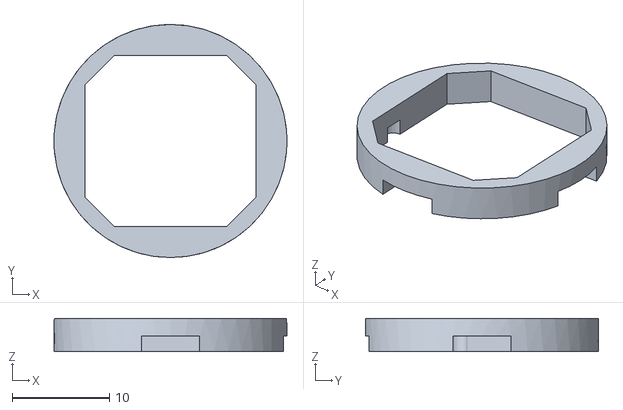
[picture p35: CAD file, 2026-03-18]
HitboardAir/02_3D_Files/More - 更多配件 /02_盖板配件/23mm摇杆封帽.stl
24.0 x 24.0 x 3.40

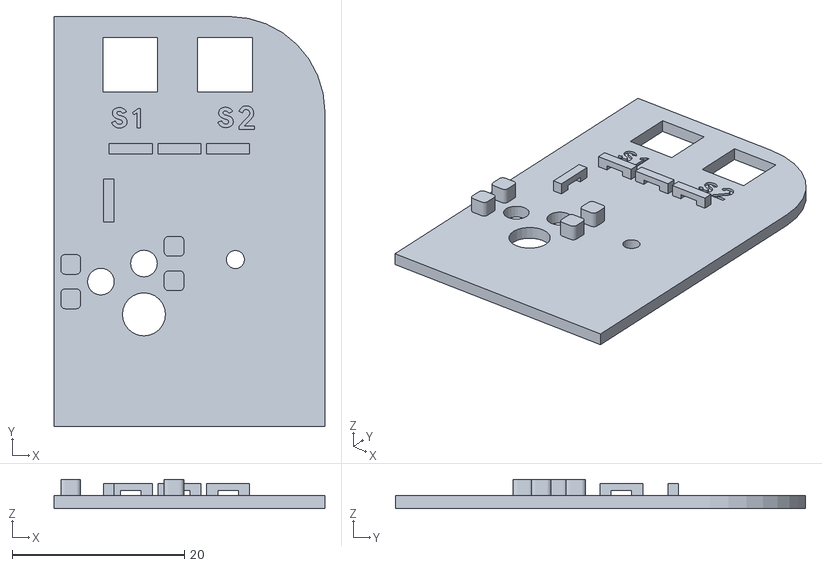
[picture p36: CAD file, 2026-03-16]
HitboardAir/02_3D_Files/More - 更多配件 /03_线路板配件/03_小板_适配微动按钮.stl
31.5 x 47.6 x 3.40

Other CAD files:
HitboardAir/02_3D_Files/Hitboard Air - 对称版（街霸特调）/硬朗线条/04_外壳.stl
HitboardAir/02_3D_Files/More - 更多配件 /05_Dock（选配）/05_Dock_下半部分.stl
HitboardAir/02_3D_Files/180x180 打印机（A1mini ）/七星版（可加 w、shift 键）/圆润/00_按键_圆润整套正打.stl
HitboardAir/02_3D_Files/180x180 打印机（A1mini ）/七星版（可加 w、shift 键）/圆润/01_盖板_右半.stl
HitboardAir/02_3D_Files/180x180 打印机（A1mini ）/七星版（可加 w、shift 键）/圆润/01_盖板_左半.stl
HitboardAir/02_3D_Files/180x180 打印机（A1mini ）/七星版（可加 w、shift 键）/圆润/02_定位板_右半.stl
HitboardAir/02_3D_Files/180x180 打印机（A1mini ）/七星版（可加 w、shift 键）/圆润/02_定位板_左半.stl
HitboardAir/02_3D_Files/180x180 打印机（A1mini ）/七星版（可加 w、shift 键）/圆润/03_线路板_右半.stl
HitboardAir/02_3D_Files/180x180 打印机（A1mini ）/七星版（可加 w、shift 键）/圆润/04_外壳_圆润_右半.stl
HitboardAir/02_3D_Files/180x180 打印机（A1mini ）/七星版（可加 w、shift 键）/圆润/04_外壳_圆润_左半.stl
HitboardAir/02_3D_Files/180x180 打印机（A1mini ）/七星版（可加 w、shift 键）/硬朗/00_按键_硬朗整套正打.stl
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

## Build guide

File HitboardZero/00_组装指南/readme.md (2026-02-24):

### HITBOARD Air - 组装指南
1. 根据「Pico 正面」的引脚示意图，或根据「Pico 背面」印刷的文字，

将每个按键的轴座的 1 个引脚接到 Pico 的任意一个 GND 焊盘（圆孔）。

//可以用一根导线串联所有轴座的 GND

2. 讲轴座的另一个引脚，接到 Pico 对应功能的焊盘（圆孔）。

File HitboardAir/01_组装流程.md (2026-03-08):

### Hitboard Air - 组装指南
0. 根据「HitboardAir 物料清单」采购对应的元器件

1.给 Pico 刷入 GP2040 固件

    按住 Pico 复位按钮的同时，通过 typec 数据线连接 Pico 到电脑。此时 Pico 将会以 U 盘的形式出现。
    
    将固件「GP2040-CE_0.7.12_Pico.uf2」文件，拖拽到 Pico U 盘。
    
    等待几秒钟，Pico 会被重新识别为手柄。可以在手柄测试网页 https://hardwaretester.com/gamepad 查看手柄状态，用导线短接 GND 和任意信号引脚查看是否工作。

2.飞线连接元器件

    物理卡位：拿出「Hitboard Air 03 线路板」，板子上布满卡扣，依次将 Pico、轴座卡在对应的位置。
    
    熟悉电路图：打开「Pico 背面」的引脚示意图，了解引脚的基本情况。
    
HitboardAir 全部打印件
    
    飞线连接：
    
        从 Pico 的任意 GND 焊盘（圆孔），引出导线，将导线依次通过每一个轴座的某个引脚（轴座有 2 个引脚任选一个），焊接确保联通（或者缠绕连接）。这样就完成了按键的接地。（功能键同理）
        
        将按键轴座另外一个引脚，接到对应的功能。比如方向键「Up」连接到 GP2。
        
        把 4 个方向键、8 个功能键、Select、Start 连到 Pico 对应的引脚。
        
        三个加键连到 Pico 的 18、19、20 引脚。//这三个引脚默认是 LS、RS、Home 功能，后续需要在设置中，改为你需要的其他按键。
        
        // 连接完成后，务必把 Pico 连接到电脑，用导线短接每个轴座的两个引脚。在手柄测试网页查看是否都能生效。
        
        // 如果不生效，检查是否虚焊，直到所有按键电路都正常工作。
        
3.组装所有板子

    拿出「Hitboard Air 04 外壳」，将 03、02，依次放入外壳。用 5mm 螺丝固定。//左上、右下的螺丝留给盖板。
    
    将轴体压入 02 定位板。//可以用手指挤压轴体左侧的外壳，让轴体不损耗卡扣
    
    放置壁纸（如果有的话）
    
    放置功能键按钮
    
    放置盖板。拧 2 颗 10mm 盖板螺丝。//最适合的螺丝是 9mm，但市面上只卖 8mm 和 10mm 的螺丝，拿钳子或者指甲刀自行打磨一下。 

按键设置：

    按住 Start 按键的同时，通过 typec 连接电脑。
    
    访问 GP2040 Web 配置界面（通过 USB 连接后访问 192.168.7.1）
    
    点击「功能配置-GPIO 引脚配置」，将 LS、RS、Home 等按键，改为需要的按键。
    
    点击引脚查看器，按下需要配置的按键，网页会显示引脚编号（如果第一次检测无效就关闭弹窗再次点击）。
        
    在按键列表中找到对应的引脚，编辑按键即可。

手柄性能设置：//必做

    点击「设置-游戏手柄设置」。
    
    将 SOCD 清理模式，改为「后输入优先」。
    
    将去抖延迟，改为 0 毫秒。

恢复出厂设置：

    取下盖板，通过定位板的复位孔，按 Pico 复位按钮的同时，通过 typec 数据线连接 Pico 到电脑。此时 Pico 将会以 U 盘的形式出现。
    
    将固件「GP2040-CE_0.7.12_Pico.uf2」文件，拖拽到 Pico U 盘。完成刷机。

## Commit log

2025-12-12 04 板子设定为 1.5mm 厚
    [Hitboard v0.16.dwg]
2025-12-19 add pcb file
    [Hitboard PCB.dxf, Hitboard v0.16.dwg]
2026-01-14 更新 v2.0 全新布局
    [Hitboard v0.16.dwg, Hitboard v0.18.dwg, Hitboard v2.dwg]
2026-01-14 文件夹修改
    [Hitboard v2.dwg]
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2026-01-17 v2.1
    - 新增 3 个加键
    - 功能键改为双大键设计
    [Hitboard v2.dwg]
2026-01-22 v0.16
    Hitboard Lite Version v0.16 更新内容：
    设计
    - 右手大拇指增加加键
    - 优化整体视觉效果
    - 更直观的 Home、Capture、L3、R3 位置
    PCB
    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
    [Hitboard v0.16.dwg, Hitboard v0.18.dwg]
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2026-01-22 readme 增加使用指南
    [Hitboard v0.16.dwg]
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2026-02-21 项目维护中...
    [Hitboard v0.16.dwg]
2026-02-21 Hitboard Zero V1
    [Hitboard v0.16.dwg]
2026-02-21 Hitboard Zero
    [Hitboard Zero V2 - v0.2 20260221.dwg, Hitboard v0.16.dwg]
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2026-02-22 增加 readme
    [Hitboard Zero v0.18.dwg, Hitboard v0.16.dwg]
2026-02-23 增加 CAD 说明
    [Hitboard Air 亚克力 v0.4.dwg]
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2026-02-24 新增「组装指南」
    [Hitboard Air v0.5 20260222 大圆角 00.stl, Hitboard Air v0.5 20260222 大圆角 01.stl, Hitboard Air v0.5 20260222 大圆角 02.stl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]
2026-02-24 支持微动按键
    [Hitboard Air 00 按键.stl, Hitboard Air 01 盖板.stl, Hitboard Air 02 定位板.stl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]
2026-02-24 组装指南
    [Hitboard Air 功能键.stl]
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2026-02-25 04 外壳 - 增加 9.7mm 厚度选项
    [Hitboard Air 04 外壳_中薄 9.7mm.stl, Hitboard Air 04 外壳_超薄 9.3mm.stl]
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2026-02-25 01 03 板子升级
    - 01 板子增加凹印大 LOGO
    - 03 板子增加凹印引脚说明
    [Hitboard Air 01 盖板.stl, Hitboard Air 03 线路板.stl, Hitboard LOGO.stl]
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2026-02-26 增加「有刻按键」
    [00_Hitboard_Air_按键无刻.stl, 00_Hitboard_Air_按键有刻.stl, 01_Hitboard_Air_盖板.stl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]
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2026-02-26 文件位置调整
    [04_Hitboard_Air_外壳中薄9.7mm.stl]
2026-02-26 新增按键文件
    [00_Hitboard_Air_按键无刻+有刻.stl]
2026-02-27 Button System 2.0
    [00_Hitboard_Air_按键无刻.stl, 00_Hitboard_Air_按键有刻.stl]
2026-02-27 正反打系统
    [00 功能键.stl, 00 拨片按键.stl, 00 无刻正反打.stl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]
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2026-02-27 增加圆润按键 Beta
    [圆润功能键.stl, 圆润拨片按键反打.stl, 圆润按键正反打.stl]
2026-02-27 线路板更新
    [03_Hitboard_Air_线路板反打.stl, 圆润按键小样正反打.stl, 硬朗按键测试小样正反打.stl]
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2026-02-28 新增带框正打按键
    [00_Hitboard_Air_圆润按键_无刻正打.stl, 00_Hitboard_Air_按键有刻反打.stl, 00_Hitboard_Air_硬朗按键_无刻反打.stl]
2026-02-28 新增按键
    [00_Hitboard_Air_圆润按键_全按键_无刻_带框_反打.stl, 00_Hitboard_Air_圆润按键_全按键_无刻_带框_正打.stl, 00_Hitboard_Air_按键无刻无框反打.stl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]
2026-02-28 更新 CAD 文件
    [01_Hitboard_Air_盖板.stl, 02_Hitboard_Air_定位板.stl, 03_Hitboard_Air_线路板_反打.stl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]
2026-02-28 边框修改为 2.4mm
    2.4mm 边框，在使用彩色外壳时，提供更稳重的色彩感。
    [01_Hitboard_Air_盖板.stl, 02_Hitboard_Air_定位板.stl, 03_Hitboard_Air_线路板_反打.stl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]
2026-03-01 圆润正打支持拨片
    [00_Hitboard_Air_圆润按键_全按键_无刻_带框_正打.stl, 00_Hitboard_Air_硬朗按键_全按键_无刻_无框_正反打.stl, 00_Hitboard_Air_硬朗按键_全按键_有刻_无框_正反打.stl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]
2026-03-01 按键框优化
    [00_Hitboard_Air_圆润按键_全按键_无刻_带框_正打.stl]
2026-03-01 按键调整
    [00_Hitboard_Air_硬朗按键_全按键_无刻_带框_正打.stl, 00_Hitboard_Air_硬朗按键_全按键_有刻_带框_反打.stl]
2026-03-02 Hitboard Air 新增：纯平按键
    [00_Hitboard_Air_硬朗按键_全按键_有刻_带框_反打.stl, 01_Hitboard_Air_盖板.stl, 02_Hitboard_Air_定位板.stl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]
2026-03-03 更新壁纸
    [纯平_23mm按键_单个.stl, 纯平_26mm按键_单个.stl.stl, 纯平_功能键键_单个.stl.stl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]
2026-03-03 优化线路板走线
    [03_Hitboard_Air_线路板_反打.stl]
2026-03-03 盖板增加 1 个螺丝孔
    [01_Hitboard_Air_盖板.stl]
2026-03-06 一大波更新
    [02_Hitboard_Air_定位板.stl, 03_Hitboard_Air_线路板_反打.stl, 04_Hitboard_Air_外壳超薄9.3mm.stl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]
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2026-03-07 3D 打印盖板新增不加键、加 1 键
    [刚01_盖板_不加键.stl, 刚01_盖板_加 1 键.stl, 刚01_盖板_加 2 键.stl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]
2026-03-08 盖板改为无螺丝孔设计
    [00_Hitboard_Air_硬朗按键_全按键_有刻_带框_反打.stl, 00_按键_无刻_反打.stl, 01_盖板_加 2 键.stl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]
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2026-03-08 文档调整
    [01_圆润_盖板_不加键.stl, 01_圆润_盖板_加 1 键.stl, 01_硬朗_盖板_不加键.stl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]
2026-03-08 优化线路板束线器
    [03_线路板_反打.stl]
2026-03-08 Dock 螺丝孔取消凸起
    更好的适配本体有螺丝的情况。
    [01_圆润_盖板_不加键.stl, 01_圆润_盖板_加 1 键.stl, 01_硬朗_盖板_不加键.stl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]
2026-03-09 支持 W 键
    [.stl, 01_盖板 W 键版.stl, 01_盖板 小手版.stl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]
2026-03-09 Creator 更新
    [Hitboard Air 亚克力 v0.9.dwg, Hitboard Air 亚克力 v08.dwg]
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2026-03-09 更新盖板文件
    [01_盖板 W 键版.stl, 01_盖板 WASD.stl, 01_盖板 低方向键.stl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]
2026-03-11 3D 打印文件调整
    20260311
    - 圆润版/硬朗版：优化 03 线路板
    - More-更多配件/03_更多线路板：增加独立的小板文件，增加不含小板的线路板文件
    [01_盖板 WASD.stl, 01_盖板 低方向键.stl, 03 线路板_不含小板.stl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]
2026-03-11 壁纸辅助线优化
    [圆润_无刻_顶面纹理随打印机.stl.stl, 硬朗_无刻_顶面纹理随打印机.stl, 硬朗_有刻_磨砂面.stl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]
2026-03-11 Air 中去除 W 键相关内容
    [01_盖板 超级低方向键.stl, 01_盖板 超级低方向键WASD.stl, Hitboard Air v0.16 20260311 七星板 01 加 W.stl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]
2026-03-12 七星 W 盖板，挖洞容纳定位板凸起
    [02_定位板.stl, 03_线路板.stl, Hitboard Air v0.16 20260311 七星板 01 加 W.stl]
2026-03-12 去除 W 盖板
    [01_盖板 超级低方向键.stl, 01_盖板 超级低方向键WASD.stl]
2026-03-12 更新定位板
    [02_定位板.stl]
2026-03-12 定位板更新
    预留发热盖板电路孔
    [02_定位板.stl]
2026-03-12 公差内测
    [Hitboard Air v0.18 20260312 公差版 01.stl, Hitboard Air v0.18 20260312 公差版 02.stl, Hitboard Air v0.18 20260312 公差版 03.stl]
2026-03-13 内测按键、增加封帽
    [01 盖板 W 加键.stl, 01 盖板.stl, 02 定位板.stl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]
2026-03-13 清理废按键
    [圆润_23mm按键_单个.stl, 圆润_26mm按键_单个.stl, 圆润_无刻_可自定义顶面纹理.stl.stl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]
2026-03-13 按键更新
    [全封（打印 2 个）.stl, 圆润_功能键_单个（打两个）.stl, 完美圆润 23mm（回字纹 8 个、螺旋纹 5 个）.stl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]
2026-03-13 按键命名
    [圆润_功能键_单个.stl, 完美圆润 23mm.stl, 完美圆润 26mm.stl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]
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2026-03-16 03 线路板、04 外壳更新
    - 线路板去除 GND 小孔，减少 3D 打印机负荷。
    - 外壳支持 Shift 加键空腔
    [03_线路板.stl, 04_外壳.stl]
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2026-03-18 修复 03 线路板缺失卡扣的问题
    [03_线路板_右半.stl, 03_线路板_左半.stl]
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2026-03-19 已知问题说明。
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2026-03-21 优化03 线路板 Right 霍尔传感器位置
    [03 线路板.stl, 03_线路板_左半.stl]
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
